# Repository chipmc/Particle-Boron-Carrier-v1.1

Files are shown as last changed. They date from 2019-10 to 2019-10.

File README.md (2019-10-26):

This carrier is to support the use of the Boron in outdoor environments.

Major functional goals for the project are:

Temp sensor in case I need to control LiPo charging
External watchdog timer - connect to either Enable or !RST
Single - button on / off so you can leave the battery and power plugged in
The ability for the device to power-cycle itself
ESD and fuse protection
Headers for i2c, SPI and IO
Big capacitor on DC-IN to support Solar Powered use case
External Real Time Clock as the Gen 3 devices lack this functionality.

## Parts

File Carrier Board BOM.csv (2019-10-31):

Part | Value | Device | Package | Description | DESCRIPTION | DESIGNER | DIGI-KEY_PART_NUMBER | DIGI-KEY_PURCHASE_URL | HOUSEPART | MANUFACTURER_PART_NUMBER | MF | MFG | MP | MPN | OC_FARNELL | OC_NEWARK | PACKAGE | POPULARITY | POPULATE | PROD_ID | REV | SF_ID | SUPPLIER | TOLERANCE | URL | VALUE | VENDOR | VOLTAGE
C1 | 0.1uF | CAP0805 | 0805@1 | Capacitor |  |  |  |  | YES |  |  |  |  | MF-CAP-0805-0.1uF |  |  |  |  | 1
C2 | 1uF | CAP0805 | 0805@1 | Capacitor |  |  |  |  |  |  |  |  |  | MF-CAP-0805-1uF
C3 | 0.1uF | CAP0805 | 0805@1 | Capacitor |  |  |  |  |  |  |  |  |  | MF-CAP-0805-0.1uF |  |  |  |  | 1
C4 | 10nF | CAP0805 | 0805@1 | Capacitor |  |  |  |  | No |  |  |  |  | 08051C103K4T2A |  |  |  |  | 1
C5 | 10nF | CAP0805 | 0805@1 | Capacitor |  |  |  |  | No |  |  |  |  | 08051C103K4T2A |  |  |  |  | 1
C6 | 0.1uF | CAP0805 | 0805@1 | Capacitor |  |  |  |  | Yes |  |  |  |  | MF-CAP-0805-0.1uF
C7 | 0.1uF | CAP0805 | 0805@1 | Capacitor |  |  |  |  | Yes |  |  |  |  | MF-CAP-0805-0.1uF
C8 | 470uF | CAPACITOR_P_10MM | CP10MM | Library: MF_Passives |  |  |  |  | 1 |  |  |  |  | MF-CAP-10MM-470uF |  |  |  |  | 1
C11 | 10pF | CAP0805 | 0805@1 | Capacitor |  |  |  |  | No |  |  |  |  | C0805C100JDGACTU‎ |  |  |  |  | 1
C12 | 8.2pF | CAP0805 | 0805@1 | Capacitor |  |  |  |  | No |  |  |  |  | C0805C829D5GACTU‎ |  |  |  |  | 1
D1 | BAT42 | DIODES_BAT42_SOD-123 | SOD-123 | Library: MF_Discrete_Semiconductor |  |  |  |  | YES |  |  |  |  | MF-DIO-SOD123-BAT42 |  |  |  |  | 1 |  |  |  |  |  | https://factory.macrofab.com/part/MF-DIO-SOD123-BAT42 | MF-DIO-SOD123-BAT42
D2 | BAT42 | DIODES_BAT42_SOD-123 | SOD-123 | Library: MF_Discrete_Semiconductor |  |  |  |  | YES |  |  |  |  | MF-DIO-SOD123-BAT42 |  |  |  |  | 1 |  |  |  |  |  | https://factory.macrofab.com/part/MF-DIO-SOD123-BAT42 | MF-DIO-SOD123-BAT42
D3 | 6.2V/500mW | DIODE-ZENER-DZ2J150M0L | PANASONIC_SMINI2-F5-B | Zener Diode |  |  |  |  |  |  |  |  |  | TDZ6V2J,115 |  |  |  |  | 1 | DIO-12989 |  |  |  |  |  | 15V
F1 | 63V/1.5A | PPTC_HALF-AMP | 1206 | Resettable Fuse PPTC |  |  |  |  |  |  |  |  |  | 046801.5NR |  |  |  |  |  | RES-08585 |  |  |  |  |  | 6V/0.5A
F2 | 6V/0.5A | PPTC_HALF-AMP | 1206 | Resettable Fuse PPTC |  |  |  |  |  |  |  |  |  | 0466.500NR |  |  |  |  |  | RES-08585 |  |  |  |  |  | 6V/0.5A
F3 | 6V/0.5A | PPTC_HALF-AMP | 1206 | Resettable Fuse PPTC |  |  |  |  |  |  |  |  |  | 0466.500NR |  |  |  |  |  | RES-08585 |  |  |  |  |  | 6V/0.5A
FD1 | FIDUCIALUFIDUCIAL | FIDUCIALUFIDUCIAL | FIDUCIAL-MICRO | Fiducial Alignment Points |  |  |  |  |  |  |  |  |  |  |  |  |  |  | 0
FD2 | FIDUCIALUFIDUCIAL | FIDUCIALUFIDUCIAL | FIDUCIAL-MICRO | Fiducial Alignment Points |  |  |  |  |  |  |  |  |  |  |  |  |  |  | 0
FRAME1 | FRAME-LETTER | FRAME-LETTER | CREATIVE_COMMONS | Schematic Frame - Letter |  |  |  |  |  |  |  |  |  |  |  |  |  |  | 0
FRAME2 | FRAME-LETTER | FRAME-LETTER | CREATIVE_COMMONS | Schematic Frame - Letter |  |  |  |  |  |  |  |  |  |  |  |  |  |  | 0
FRAME3 | FRAME-LETTER | FRAME-LETTER | CREATIVE_COMMONS | Schematic Frame - Letter |  |  |  |  |  |  |  |  |  |  |  |  |  |  | 0
G1 | D5V0L4B5TS | D5V0L4B5TS | SOT-23-5 | 4 CHANNEL LOW CAPACITANCE BI-DIRECTIONAL TVS ARRAY |  |  |  |  |  |  |  |  |  | D5V0L4B5TS-7
H1 | STAND-OFF-M2.5 | STAND-OFF-M2.5 | STAND-OFF-M2.5 | Stand Off |  |  |  |  |  |  |  |  |  |  |  |  |  |  | 0
H2 | STAND-OFF-M2.5 | STAND-OFF-M2.5 | STAND-OFF-M2.5 | Stand Off |  |  |  |  |  |  |  |  |  |  |  |  |  |  | 0
H3 | STAND-OFF-M2.5 | STAND-OFF-M2.5 | STAND-OFF-M2.5 | Stand Off |  |  |  |  |  |  |  |  |  |  |  |  |  |  | 0
H4 | STAND-OFF-M2.5 | STAND-OFF-M2.5 | STAND-OFF-M2.5 | Stand Off |  |  |  |  |  |  |  |  |  |  |  |  |  |  | 0
J1 | H4P-SMD-2.0 | GROVE-CONNECTOR-SMD(4+2P-2.0) | HW4-SMD-2.0 | 320110030 |  |  |  |  |  |  |  |  |  | B4B-PH-SM4-TB(LF)(SN) |  |  |  |  | 1 |  |  |  |  |  |  | H4P-SMD-2.0
J2 |  | CONN_03X22X3_SILK_MALE_PTH | 2X3 | Multi connection point. Often used as Generic Header-pin footprint for 0.1 inch spaced/style header connections |  |  |  |  |  |  |  |  |  |  |  |  |  |  | 0 | CONN-09701
J3 | H4P-SMD-2.0 | GROVE-CONNECTOR-SMD(4+2P-2.0) | HW4-SMD-2.0 | 320110030 |  |  |  |  |  |  |  |  |  | B4B-PH-SM4-TB(LF)(SN) |  |  |  |  | 1 |  |  |  |  |  |  | H4P-SMD-2.0
J4 | S2B-PH-SM4-TB(LF)(SN) | JST_2MM_MALE | JST-2-SMD | JST 2MM MALE RA CONNECTOR |  |  |  |  |  |  |  | JST S2B-PH-SM4-TB(LF)(SN) |  |  |  |  |  |  |  | CONN-11443 |  | PRT-08612
J5 | S2B-PH-SM4-TB(LF)(SN) | JST_2MM_MALE | JST-2-SMD | JST 2MM MALE RA CONNECTOR |  |  |  |  |  |  |  | JST S2B-PH-SM4-TB(LF)(SN) |  |  |  |  |  |  |  | CONN-11443 |  | PRT-08612
J6 | H4P-SMD-2.0 | GROVE-CONNECTOR-SMD(4+2P-2.0) | HW4-SMD-2.0 | 320110030 |  |  |  |  |  |  |  |  |  | B4B-PH-SM4-TB(LF)(SN) |  |  |  |  | 1 |  |  |  |  |  |  | H4P-SMD-2.0
J7 |  | M06LOCK | 1X06_LOCK | Header 6 |  |  |  |  |  |  |  |  |  |  |  |  |  |  | 0
JP1 | JUMPER-SMT_2_NC_PASTE_SILK | JUMPER-SMT_2_NC_PASTE_SILK | SMT-JUMPER_2_NC_PASTE_SILK | Normally closed solder jumper |  |  |  |  |  |  |  |  |  |  |  |  |  |  | 0
JP3 | STAND-OFF | STAND-OFF | STAND-OFF | Stand Off |  |  |  |  |  |  |  |  |  |  |  |  |  |  | 0
JP4 | STAND-OFF | STAND-OFF | STAND-OFF | Stand Off |  |  |  |  |  |  |  |  |  |  |  |  |  |  | 0
JP5 | STAND-OFF | STAND-OFF | STAND-OFF | Stand Off |  |  |  |  |  |  |  |  |  |  |  |  |  |  | 0
JP6 | STAND-OFF | STAND-OFF | STAND-OFF | Stand Off |  |  |  |  |  |  |  |  |  |  |  |  |  |  | 0
JP7 | JUMPER-SMT_2_NC_PASTE_SILK | JUMPER-SMT_2_NC_PASTE_SILK | SMT-JUMPER_2_NC_PASTE_SILK | Normally closed solder jumper |  |  |  |  |  |  |  |  |  |  |  |  |  |  | 0
P1 | PARTICLE-DEVICES-BORON | PARTICLE-DEVICES-BORON | PARTICLE-DEVICES_BORON | Particle Boron Device for Carrier Board Placement |  |  |  |  |  |  |  |  |  |  |  |  |  |  | 0
Q1 | BSS138 | BSS123 | SOT23 | N-CHANNEL MOS FET |  |  |  |  | Yes |  |  |  |  | MF-DSC-SOT233-BSS138 |  |  |  | 21
Q2 | BSS138 | BSS123 | SOT23 | N-CHANNEL MOS FET |  |  |  |  | Yes |  |  |  |  | MF-DSC-SOT233-BSS138 |  |  |  | 21
R1 | 270k | RESISTOR0805-RES | 0805 | Resistor |  |  |  |  |  |  |  |  |  | ERJ-P06F2703V
R2 | 270k | RESISTOR0805-RES | 0805 | Resistor |  |  |  |  |  |  |  |  |  | ERJ-P06F2703V
R3 | 100k | RESISTOR0805-RES | 0805 | Resistor |  |  |  |  | YES |  |  |  |  | MF-RES-0805-100K
R4 | 4.7k | RESISTOR0805-RES | 0805 | Resistor |  |  |  |  |  |  |  |  |  | MF-RES-0805-4.7K
R5 | 4.7k | RESISTOR0805-RES | 0805 | Resistor |  |  |  |  |  |  |  |  |  | MF-RES-0805-4.7K
R6 | 100k | RESISTOR0805-RES | 0805 | Resistor |  |  |  |  | YES |  |  |  |  | MF-RES-0805-100K
R7 | 10k | RESISTOR0805-RES | 0805 | Resistor |  |  |  |  | YES |  |  |  |  | MF-RES-0805-10K
R8 | 100 | RESISTOR0805-RES | 0805 | Resistor |  |  |  |  | Yes |  |  |  |  | MF-RES-0805-100
R9 | 100 | RESISTOR0805-RES | 0805 | Resistor |  |  |  |  | Yes |  |  |  |  | MF-RES-0805-100
R20 | 10k | RESISTOR0805-RES | 0805 | Resistor |  |  |  |  | YES |  |  |  |  | MF-RES-0805-10K
R21 | 10k | RESISTOR0805-RES | 0805 | Resistor |  |  |  |  | YES |  |  |  |  | MF-RES-0805-10K
R22 | 10k | RESISTOR0805-RES | 0805 | Resistor |  |  |  |  | YES |  |  |  |  | MF-RES-0805-10K
S1 |  | SWITCH-SPDT-SMD-AYZ0202 | SWITCH_DPDT_SMD_AYZ0202 | Single Pole, Double Throw (SPDT) Switch |  |  |  |  |  |  |  |  |  | AYZ0202AGRLC |  |  |  |  |  | SWCH-08179 |  | COM-00597
SW1 | MF-SW-TACT-6MM | TACT_6MM | TACT6MM | Library: MF_Switches |  |  |  |  | YES |  |  |  |  | MF-SW-TACT-6MM |  |  |  |  | 1 |  |  |  |  |  | https://factory.macrofab.com/part/MF-SW-TACT-6MM | MF-SW-TACT-6MM
U1 | TMP36GRTZ | TMP36GRTZ-REEL7 | RJ_5 |  |  |  |  |  |  | TMP36GRTZ-REEL7 |  |  |  | TMP36GRTZ-REEL7 |  |  |  |  |  |  |  |  |  |  |  |  | Analog Devices Inc
U2 | MB85RC64 | MB85RC128PNF-G-JNE1 | SOIC127P600X175-8N | Memory FRAM |  |  |  |  |  |  |  |  |  | MB85RC64PNF-G-JNE1 | 1831995 | 93R5161 | SO-8 |  |  |  |  |  | FUJITSU
U3 | TPL5010 | TPL5010 | TSOT-23 | This is a TI Ultra-Low-Power External watchdog. |  |  |  |  |  |  |  |  |  | TPL5010DDCR |  |  |  |  | 1
U4 | TPS22810 | TPS22810 | SOT-23-6 | TPS22810, 2.7-18-V, 79-mΩOn-ResistanceLoadSwitchWithThermal Protection |  |  |  |  |  |  |  |  |  | TPS22810DBVT
U5 | TPS22810 | TPS22810 | SOT-23-6 | TPS22810, 2.7-18-V, 79-mΩOn-ResistanceLoadSwitchWithThermal Protection |  |  |  |  |  |  |  |  |  | TPS22810DBVT
U7 | NL17SZ74USG | NL17SZ74USG | SOP50P310X90-8N | Single D Flip Flop | NL17SZ Series 3.25 V Surface Mount Single D-Type Flip-Flop - US-8 |  | NL17SZ74USGOSCT-ND | https://www.digikey.com/product-detail/en/on-semiconductor/NL17SZ74USG/NL17SZ74USGOSCT-ND/1139964 |  |  | ON Semiconductor |  | NL17SZ74USG |  |  |  | VFSOP-8 ON Semiconductor
U8 | MCP79410T-I/SN | MCP79410T-I/SN | SOIC8-N_MC |  |  |  |  |  |  | MCP79410TISN |  |  |  |  |  |  |  |  | 1 |  |  |  |  |  |  |  | Microchip
V1 | VC080505C150DP | VARISTOR | 0805 |  |  |  |  |  |  |  |  |  |  | VC080505C150DP
V2 | VC080505C150DP | VARISTOR | 0805 |  |  |  |  |  |  |  |  |  |  | VC080505C150DP
V3 | VC080505C150DP | VARISTOR | 0805 |  |  |  |  |  |  |  |  |  |  | VC080505C150DP
Y1 | ECS-.327-6-17X-TR | ECS-.327-6-17X-TR | XTAL_ECS-.327-6-17X-TR | Crystal 4-SOJ, 5.50mm pitch | ECX-306X Series 32.768 kHz ±20 ppm 6 pF -40 to +85 °C SMT Tuning Fork Crystal |  | XC1307CT-ND | https://www.digikey.com/product-detail/en/ecs-inc/ECS-.327-6-17X-TR/XC1307CT-ND/827771 |  |  | ECS Inc. |  | ECS-.327-6-17X-TR |  |  |  | 4-4 ECS International

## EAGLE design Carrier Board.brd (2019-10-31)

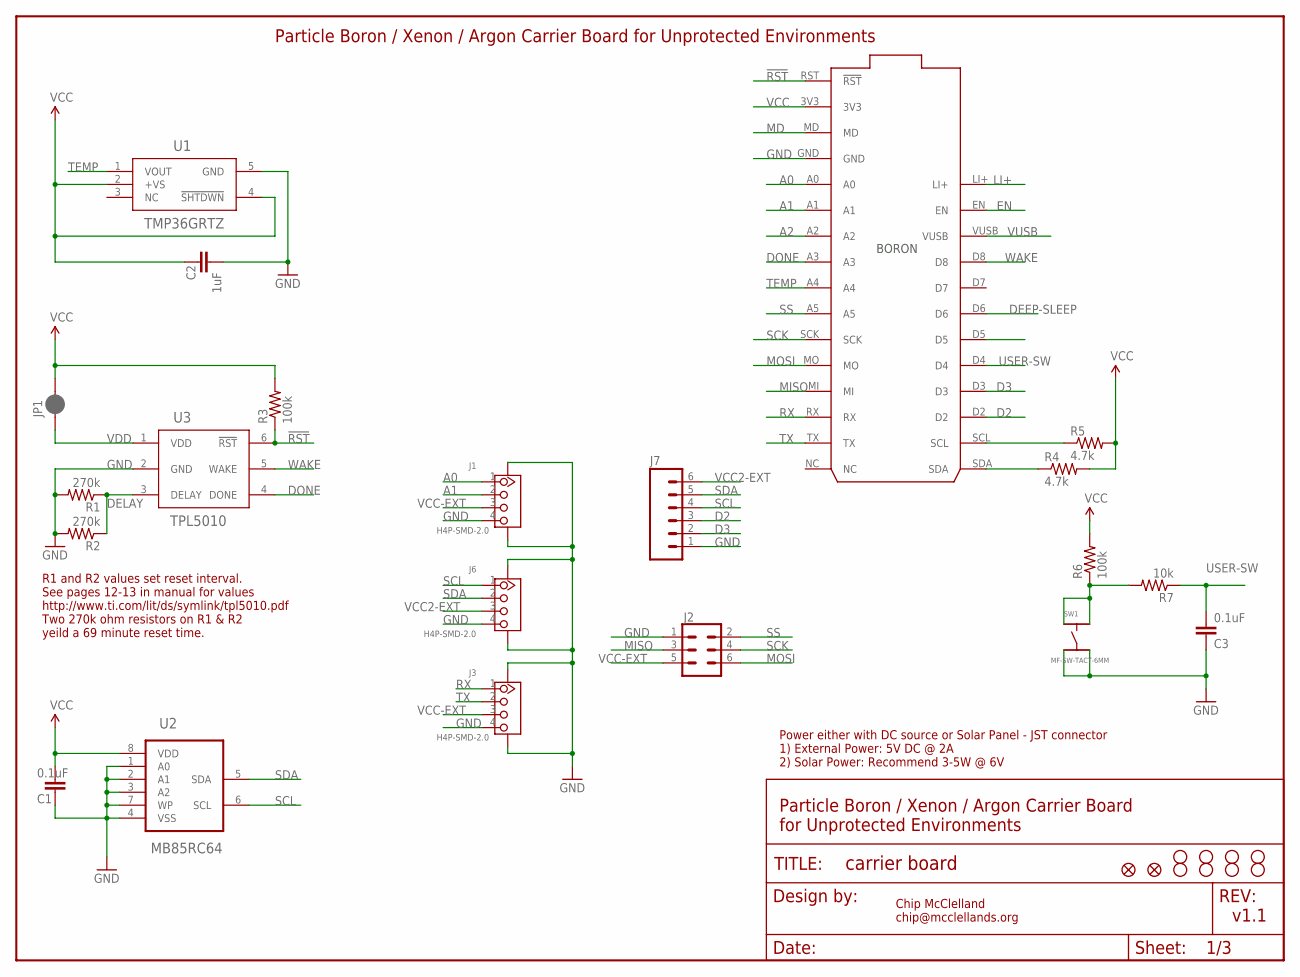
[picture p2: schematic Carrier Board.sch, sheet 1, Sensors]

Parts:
C1, C3: 0.1uF; 0805@1; MPN MF-CAP-0805-0.1uF
C2: 1uF; 0805@1; MPN MF-CAP-0805-1uF
FD1, FD2: FIDUCIALUFIDUCIAL; FIDUCIAL-MICRO
FRAME1: FRAME-LETTER; CREATIVE_COMMONS
H1, H2, H3, H4: STAND-OFF-M2.5
J1, J3, J6: H4P-SMD-2.0; HW4-SMD-2.0; MPN B4B-PH-SM4-TB(LF)(SN)
J2: CONN_03X22X3_SILK_MALE_PTH; 2X3
J7: M06LOCK; 1X06_LOCK
JP1: JUMPER-SMT_2_NC_PASTE_SILK; SMT-JUMPER_2_NC_PASTE_SILK
JP3, JP4, JP5, JP6: STAND-OFF
P1: PARTICLE-DEVICES-BORON; PARTICLE-DEVICES_BORON
R1, R2: 270k; 0805; MPN ERJ-P06F2703V
R3, R6: 100k; 0805; MPN MF-RES-0805-100K
R4, R5: 4.7k; 0805; MPN MF-RES-0805-4.7K
R7: 10k; 0805; MPN MF-RES-0805-10K
SW1: MF-SW-TACT-6MM; TACT6MM
U1: TMP36GRTZ; RJ_5; MANUFACTURER_PART_NUMBER TMP36GRTZ-REEL7
U2: MB85RC64; SOIC127P600X175-8N; MPN MB85RC64PNF-G-JNE1
U3: TPL5010; TSOT-23; MPN TPL5010DDCR

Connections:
!RST: P1.RST (!RST), R3.1, U3.6 (!RST)
A0: J1.1, P1.A0
A1: J1.2, P1.A1
A2: P1.A2
D2: J7.3, P1.D2; also elsewhere on the board
D3: J7.2, P1.D3; also elsewhere on the board
DEEP-SLEEP: P1.D6; also elsewhere on the board
DELAY: R1.1, R2.1, U3.3 (DELAY)
DONE: P1.A3, U3.4 (DONE)
EN: P1.EN; also elsewhere on the board
GND: C1.2, C2.2, C3.2, J1.4, J1.SS1, J1.SS2, J2.1, J3.4, J3.SS1, J3.SS2, J6.4, J6.SS1, J6.SS2, J7.1, P1.GND, R1.2, R2.2, SW1.P$3, SW1.P$4, U1.5 (GND), U2.1 (A0), U2.2 (A1), U2.3 (A2), U2.4 (VSS), U2.7 (WP), U3.2 (GND); also elsewhere on the board
LI+: P1.LI+; also elsewhere on the board
MD: P1.MD
MISO: J2.3, P1.MI
MOSI: J2.6, P1.MO
unnamed: R6.1, R7.2, SW1.P$1, SW1.P$2
RX: J3.1, P1.RX
SCK: J2.4, P1.SCK
SCL: J6.1, J7.4, P1.SCL, R5.1, U2.6 (SCL); also elsewhere on the board
SDA: J6.2, J7.5, P1.SDA, R4.1, U2.5 (SDA); also elsewhere on the board
SS: J2.2, P1.A5
TEMP: P1.A4, U1.1 (VOUT)
TX: J3.2, P1.TX
USER-SW: C3.1, P1.D4, R7.1
VCC: C1.1, C2.1, JP1.2, P1.3V3, R3.2, R4.2, R5.2, R6.2, U1.2 (+VS), U1.4 (!SHTDWN), U2.8 (VDD); also elsewhere on the board
VCC2-EXT: J6.3, J7.6; also elsewhere on the board
VCC-EXT: J1.3, J2.5, J3.3; also elsewhere on the board
VDD: JP1.1, U3.1 (VDD)
VUSB: P1.VUSB; also elsewhere on the board
WAKE: P1.D8, U3.5 (WAKE)

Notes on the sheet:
Chip McClelland chip@mcclellands.org
v1.1
Power either with DC source or Solar Panel - JST connector 1) External Power: 5V DC @ 2A 2) Solar Power: Recommend 3-5W @ 6V
Particle Boron / Xenon / Argon Carrier Board for Unprotected Environments
R1 and R2 values set reset interval. See pages 12-13 in manual for values http://www.ti.com/lit/ds/symlink/tpl5010.pdf Two 270k ohm resistors on R1 & R2 yeild a 69 minute reset time.
Particle Boron / Xenon / Argon Carrier Board for Unprotected Environments

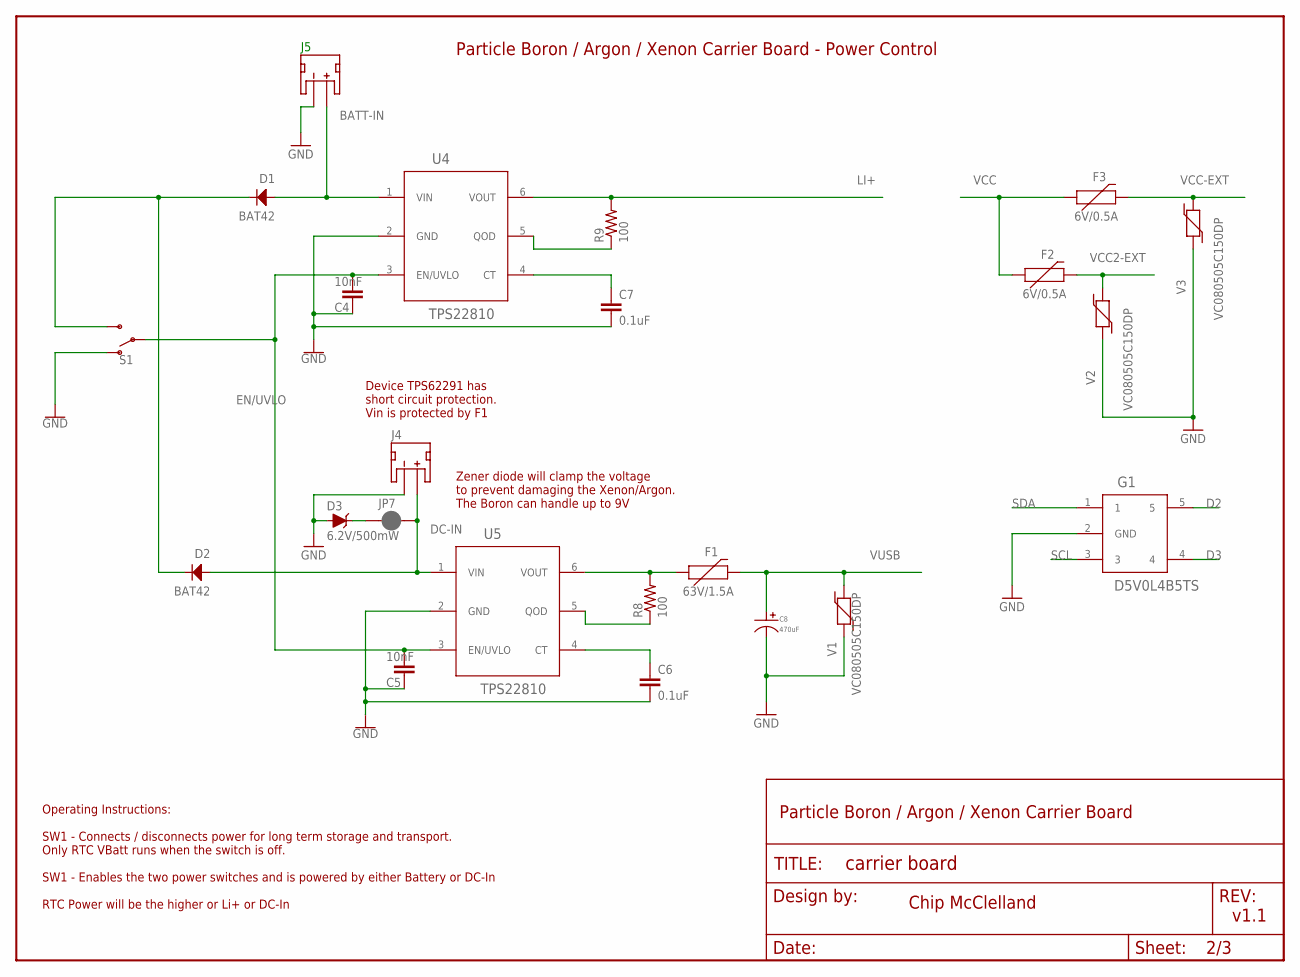
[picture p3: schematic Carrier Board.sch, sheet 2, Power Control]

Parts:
C4, C5: 10nF; 0805@1; MPN 08051C103K4T2A
C6, C7: 0.1uF; 0805@1; MPN MF-CAP-0805-0.1uF
C8: 470uF; CP10MM; MPN MF-CAP-10MM-470uF
D1, D2: BAT42; SOD-123
D3: 6.2V/500mW; PANASONIC_SMINI2-F5-B; MPN TDZ6V2J,115
F1: 63V/1.5A; 1206; MPN 046801.5NR
F2, F3: 6V/0.5A; 1206; MPN 0466.500NR
FRAME2: FRAME-LETTER; CREATIVE_COMMONS
G1: D5V0L4B5TS; SOT-23-5; MPN D5V0L4B5TS-7
J4, J5: S2B-PH-SM4-TB(LF)(SN); JST-2-SMD
JP7: JUMPER-SMT_2_NC_PASTE_SILK; SMT-JUMPER_2_NC_PASTE_SILK
R8, R9: 100; 0805; MPN MF-RES-0805-100
S1: SWITCH-SPDT-SMD-AYZ0202; SWITCH_DPDT_SMD_AYZ0202; MPN AYZ0202AGRLC
U4, U5: TPS22810; SOT-23-6; MPN TPS22810DBVT
V1, V2, V3: VC080505C150DP; 0805; MPN VC080505C150DP

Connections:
BATT-IN: D1.ANODE, J5.2 (+), U4.1 (VIN); also elsewhere on the board
D2: G1.5; also elsewhere on the board
D3: G1.4; also elsewhere on the board
DC-IN: D2.ANODE, J4.2 (+), JP7.1, U5.1 (VIN)
EN/UVLO: C4.1, C5.1, S1.2, U4.3 (EN/UVLO), U5.3 (EN/UVLO)
GND: C4.2, C5.2, C6.2, C7.2, C8.P$2, D3.A, G1.2 (GND), J4.1 (-), J5.1 (-), S1.1 (O), U4.2 (GND), U5.2 (GND), V1.1, V2.1, V3.1; also elsewhere on the board
LI+: R9.2, U4.6 (VOUT); also elsewhere on the board
unnamed: D3.C, JP7.2
unnamed: C6.1, U5.4 (CT)
unnamed: R8.1, U5.5 (QOD)
unnamed: F1.1, R8.2, U5.6 (VOUT)
unnamed: D1.CATHODE, D2.CATHODE, S1.3 (S)
unnamed: C7.1, U4.4 (CT)
unnamed: R9.1, U4.5 (QOD)
SCL: G1.3; also elsewhere on the board
SDA: G1.1; also elsewhere on the board
VCC: F2.1, F3.1; also elsewhere on the board
VCC2-EXT: F2.2, V2.2; also elsewhere on the board
VCC-EXT: F3.2, V3.2; also elsewhere on the board
VUSB: C8.P$1, F1.2, V1.2; also elsewhere on the board

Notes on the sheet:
Particle Boron / Argon / Xenon Carrier Board - Power Control
Chip McClelland
v1.1
Device TPS62291 has short circuit protection. Vin is protected by F1
Particle Boron / Argon / Xenon Carrier Board
Operating Instructions: SW1 - Connects / disconnects power for long term storage and transport. Only RTC VBatt runs when the switch is off. SW1 - Enables the two power switches and is powered by either Battery or DC-In RTC Power will be the higher or Li+ or DC-In
Zener diode will clamp the voltage to prevent damaging the Xenon/Argon. The Boron can handle up to 9V

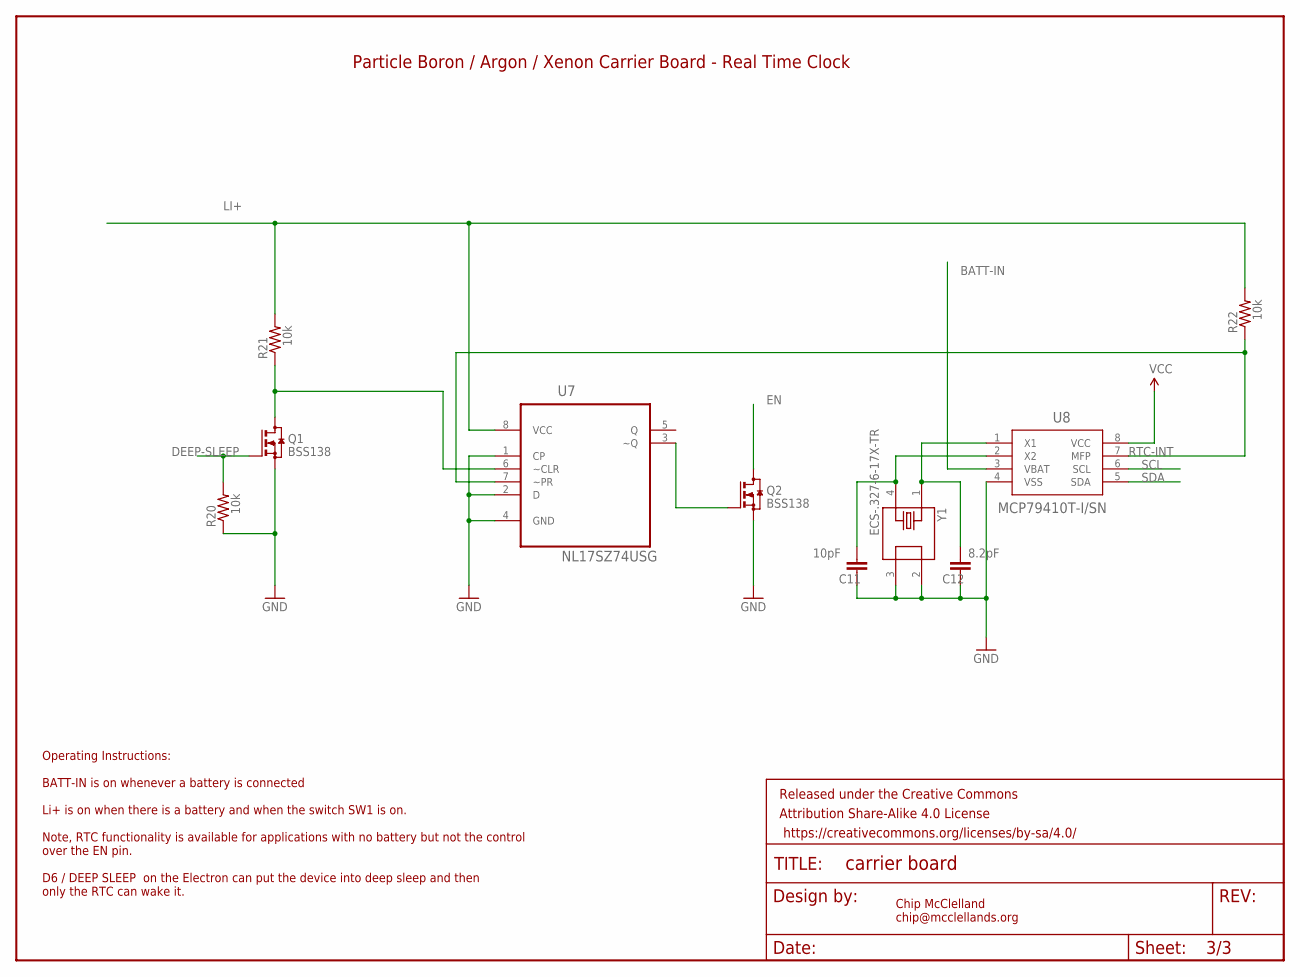
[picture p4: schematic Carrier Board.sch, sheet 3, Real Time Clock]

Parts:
C11: 10pF; 0805@1; MPN C0805C100JDGACTU‎
C12: 8.2pF; 0805@1; MPN C0805C829D5GACTU‎
FRAME3: FRAME-LETTER; CREATIVE_COMMONS
Q1, Q2: BSS138; SOT23; MPN MF-DSC-SOT233-BSS138
R20, R21, R22: 10k; 0805; MPN MF-RES-0805-10K
U7: NL17SZ74USG; SOP50P310X90-8N
U8: MCP79410T-I/SN; SOIC8-N_MC
Y1: ECS-.327-6-17X-TR; XTAL_ECS-.327-6-17X-TR

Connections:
BATT-IN: U8.3 (VBAT); also elsewhere on the board
DEEP-SLEEP: Q1.1 (G), R20.2; also elsewhere on the board
EN: Q2.3 (D); also elsewhere on the board
GND: C11.2, C12.2, Q1.2 (S), Q2.2 (S), R20.1, U7.1 (CP), U7.2 (D), U7.4 (GND), U8.4 (VSS), Y1.2, Y1.3; also elsewhere on the board
LI+: R21.2, R22.2, U7.8 (VCC); also elsewhere on the board
unnamed: Q2.1 (G), U7.3 (~Q)
unnamed: Q1.3 (D), R21.1, U7.6 (~CLR)
unnamed: C12.1, U8.1 (X1), Y1.1
unnamed: C11.1, U8.2 (X2), Y1.4
RTC-INT: R22.1, U7.7 (~PR), U8.7 (MFP)
SCL: U8.6 (SCL); also elsewhere on the board
SDA: U8.5 (SDA); also elsewhere on the board
VCC: U8.8 (VCC); also elsewhere on the board

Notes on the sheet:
Operating Instructions: BATT-IN is on whenever a battery is connected Li+ is on when there is a battery and when the switch SW1 is on. Note, RTC functionality is available for applications with no battery but not the control over the EN pin. D6 / DEEP SLEEP on the Electron can put the device into d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
Particle Boron / Argon / Xenon Carrier Board - Real Time Clock
Chip McClelland chip@mcclellands.org

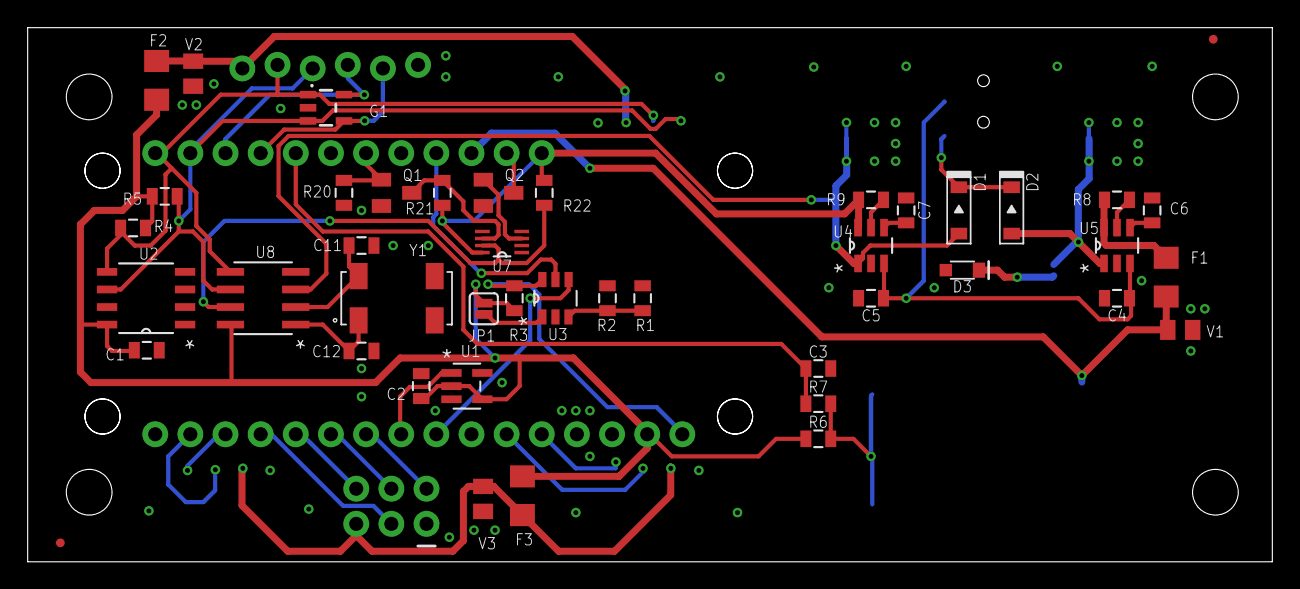
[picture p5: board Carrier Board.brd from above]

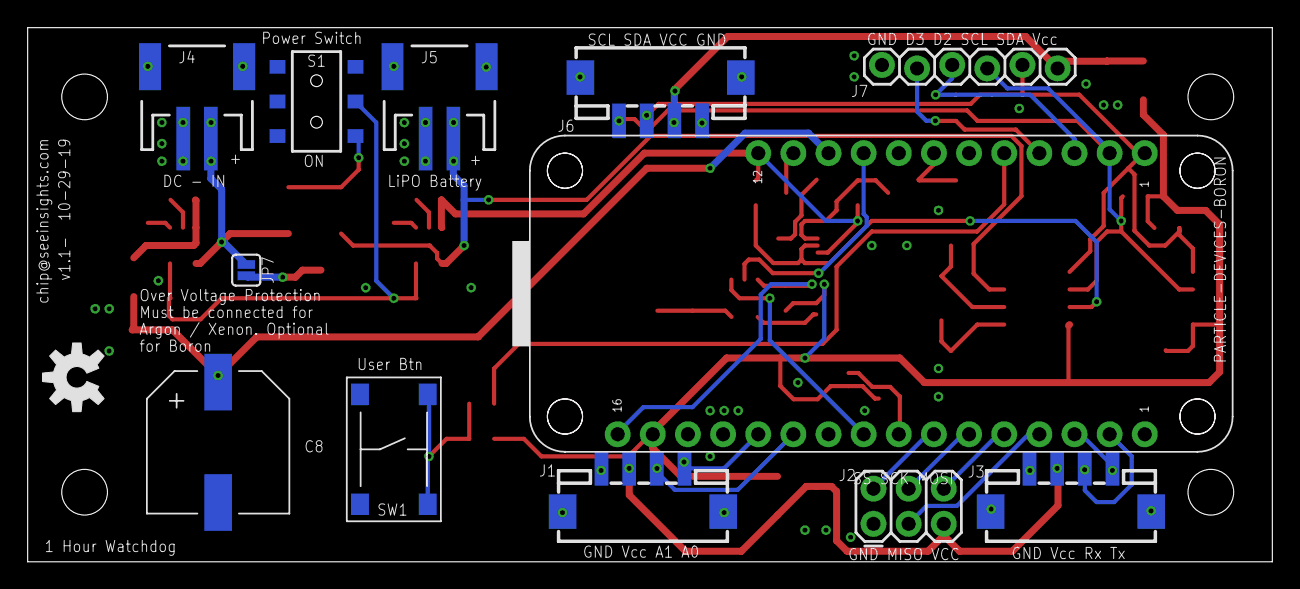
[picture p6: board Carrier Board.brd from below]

Board: 2 copper layers, 90.0 x 38.6 mm, 68 parts (13 on the bottom side), 43 nets.

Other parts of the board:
U$2: OSHW-LOGO-M

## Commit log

2019-09-19 v1.1 - Added a GND pin to serial
    [Carrier Board.brd, Carrier Board.sch]
2019-09-19 Fixed Analoge Header Pins
    [Carrier Board.brd, Carrier Board.sch]
2019-10-26 Next major revision - Added RTC
    [Carrier Board.brd, Carrier Board.sch, Maqam v2.brd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]
2019-10-29 Added Zener protection for Argon / Xenon
    [Carrier Board.brd, Carrier Board.sch]
2019-10-31 Final Tweaks before MacroFab
    [Carrier Board.brd, Carrier Board.sch]
2019-10-31 Version 1.1 with BOM / Gerbers for prototype run.
    [Carrier Board BOM.csv, Carrier Board.csv]

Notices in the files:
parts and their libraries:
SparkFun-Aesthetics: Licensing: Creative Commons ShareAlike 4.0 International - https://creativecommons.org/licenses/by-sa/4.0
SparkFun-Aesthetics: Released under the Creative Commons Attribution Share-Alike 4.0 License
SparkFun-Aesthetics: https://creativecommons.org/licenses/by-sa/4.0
